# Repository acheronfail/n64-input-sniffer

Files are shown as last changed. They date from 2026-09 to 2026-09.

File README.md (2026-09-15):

# NintendoSpy N64 reader — ESP32

## How it works

The adapter reads input from up to four Nintendo 64 (N64) controllers and shows their buttons and stick positions in a browser.
It connects between the console and controllers without changing their signals.
The console must run and poll the controllers for input to appear.

## Setup

### Wiring

> [!WARNING]
> **Do not connect USB-C while the adapter is connected to the N64 console.**
> Fully disconnect the adapter from **all four console ports** before connecting USB-C to a computer or USB power source. Disconnect USB-C before reconnecting the adapter to the console.
>
> **Turning the console off is not enough.** USB power can backfeed the console’s 3.3V rail and potentially damage hardware. The 470 µF capacitor does not prevent backfeeding.

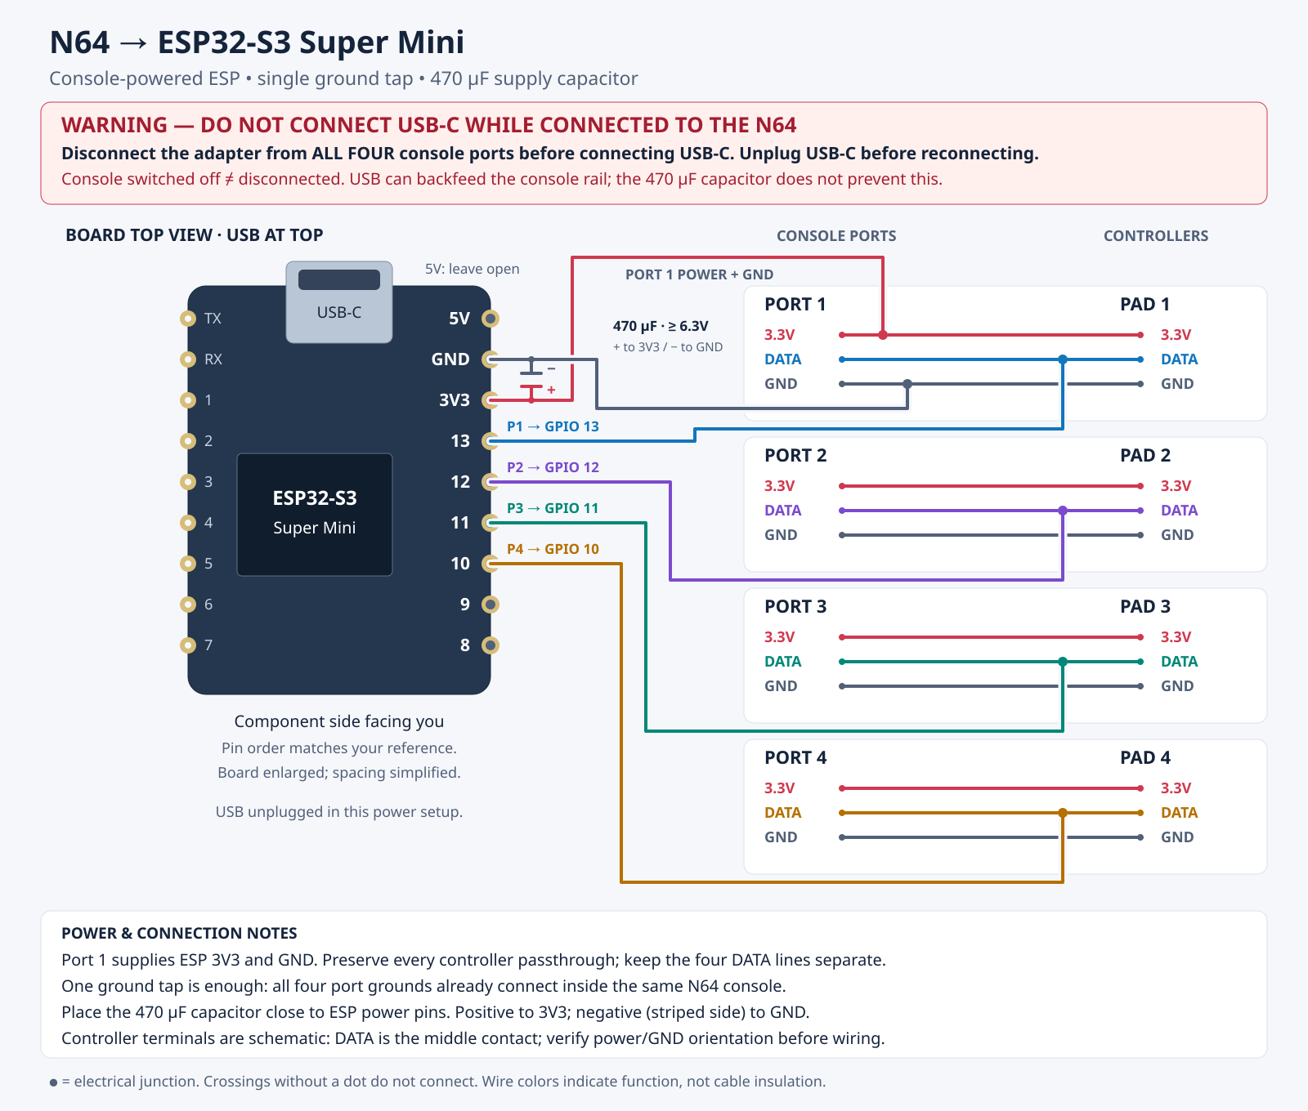
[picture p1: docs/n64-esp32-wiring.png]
Four-controller passthrough wiring


[Download the wiring diagram (SVG)](docs/n64-esp32-wiring.svg).
The diagram shows the component side of the Super Mini board, with USB at the top.

| Connection | ESP32 pin |
| --- | --- |
| Port 1 DATA (middle pin) | GPIO 13 |
| Port 2 DATA (middle pin) | GPIO 12 |
| Port 3 DATA (middle pin) | GPIO 11 |
| Port 4 DATA (middle pin) | GPIO 10 |
| 3.3V from one console port | 3V3 |
| GND from the same console port | GND |

1. Connect the DATA lines as shown in the diagram and table.
2. Connect one console port's 3.3V and GND to the ESP32.
   Keep each controller's power and ground passthrough connections.
3. Connect a **470 µF electrolytic capacitor**, rated at least **6.3V**, across ESP32 3V3 and GND.
   Place it close to the board with short leads.
   Connect **positive (+) to 3V3**. Connect **negative (striped side) to GND**.
4. Leave the ESP32 **5V pin unconnected**.

### Install the firmware

Install PlatformIO, Node.js 22.12 or later, and npm on your computer.

**Before connecting USB-C, disconnect the adapter from all four console ports—even if the console is off.**

1. Connect the ESP32 to your computer through USB-C.
2. From the project directory, build and upload the firmware:

   ```sh
   pio run -t upload
   ```

3. Disconnect USB-C.
4. Connect the adapter to the console and controllers.
5. Turn on the console.

### Connect to WiFi

1. On first boot, join the open **`N64Spy-Setup`** WiFi network from a phone or laptop.
   The setup page opens automatically.
2. Select your WiFi network on the setup page.
3. Enter the network password.
4. Save the credentials.
   The adapter saves them and reconnects automatically on later boots.
5. Open [n64spy.local](http://n64spy.local/) in a browser to view controller input.

To change networks, hold **BOOT** for about **3 seconds** at startup or during normal operation.
The adapter deletes the saved network and restarts WiFi setup.
You can also use the controller input code below.

## LED sequences

| State | LED sequence |
| ----- | --- |
| Normal power | Solid red, unless disabled with the input code below. |
| WiFi setup waits for credentials | Red, 500 ms on / 500 ms off, repeating. |
| WiFi connects or reconnects | Blue, 500 ms on / 500 ms off, repeating. |
| WiFi connected | Two green flashes, 250 ms on / 250 ms off, then the normal power setting. |
| WiFi connection failed or lost | Three red flashes, 125 ms on / 125 ms off, then the connection or setup sequence. |
| Command mode | Solid green for up to 5 seconds. |
| Command accepted | Four magenta flashes, 125 ms on / 125 ms off, then the command takes effect. |

WiFi and command feedback still show when the normal red power LED is disabled.
Command feedback takes priority over WiFi status.

## Controller input codes

Commands are available after the initial WiFi setup completes, while the console runs and polls the controller.
These button presses also reach the game.

1. Push **L + R + D-pad down** together on any controller.
   The LED turns **green** for up to **5 seconds**.
2. Within that time, push one command button on the **same controller**.
   You can release the entry combination first.

| Button | Action |
| --- | --- |
| **START** | Delete saved WiFi credentials and reboot into **N64Spy-Setup**. |
| **Z** | Switch the normal red power LED on or off. The setting stays saved after a reboot. |

An accepted command ends command mode and shows the magenta confirmation sequence before it takes effect.
If you already held the command button when command mode started, release it before you push it again.
Other buttons and simultaneous **START + Z** presses do not select a command.

If five seconds pass without a command, the LED returns to its normal setting.
To enter command mode again, release **L + R + D-pad down**, then push the combination again.

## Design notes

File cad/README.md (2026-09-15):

# CAD release

The v1.2 enclosure moves the ESP and its supports 2 mm toward the USB-C wall.
**Status: verified.** The owner printed v1.2 and marked it verified on 2026-09-15.
The v1.1 release stays available.

- [v1.2 FreeCAD model](Enclosure/Enclosure-v1.2.FCStd)
- [v1.2 print project](Enclosure/Enclosure-full-enclosure-v1.2-Orca-complete.3mf)

The tested **v1.1** enclosure leaves at least 2 mm between opposing keeper towers.
It moves the ESP window 4 mm toward the N64 edge and moves four closure bolts toward that edge.
The matching jig has an 18.1 mm connector gap.
**Status: verified.** The owner confirmed that both printed v1.1 parts work on 2026-09-15.
Physical verification applies to the retained v1.1 release files.
Generated reports describe digital checks only. Future geometry changes need new physical tests.

The physically tested [v1.0 enclosure](Enclosure/Enclosure-v1.0.FCStd) and [v1.0 print project](Enclosure/Enclosure-full-enclosure-v1.0-Orca-complete.3mf) remain unchanged.

- [Enclosure FreeCAD model](Enclosure/Enclosure-v1.1.FCStd)
- [Enclosure print-ready OrcaSlicer 3MF](Enclosure/Enclosure-full-enclosure-v1.1-Orca-complete.3mf)
- [Enclosure print and assembly instructions](Enclosure/README.md)
- [Soldering jig model, print project, and instructions](SolderingJig/README.md)
- Latest [female connector](n64-input-ControllerPortFemale.step) and [male connector](n64-input-ControllerPortMale.step) STEP models
- [Male housing-only reference](n64-input-ControllerPortMale-housing.step), the seating datum for the enclosure and jig

Both FreeCAD documents embed their shapes and references.
You need no external scans or build scripts to open them.
These documents contain saved solid models, not a history of constrained sketches.
Changes to the embedded parameter snapshot alone do not regenerate geometry.

The current Python build, geometry checks, and print export scripts remain beside each model.
See the [development instructions](DEVELOPMENT.md) to regenerate and revise the models.
Historical revisions and duplicate generated exports are omitted.

The enclosure contains reduced display meshes from [Wesk's N64 console scan](https://bitbuilt.net/forums/threads/n64-console-scan.5527/).
Their alignment is approximate.

See the [repository README](../README.md) for wiring and firmware.

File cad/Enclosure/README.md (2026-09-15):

# Enclosure v1.2

**Status: verified.** The owner printed v1.2 and marked it verified on 2026-09-15.
The owner tested the retained v1.1 print on 2026-09-15.

[FreeCAD model](Enclosure-v1.2.FCStd) · [Print-ready OrcaSlicer 3MF](Enclosure-full-enclosure-v1.2-Orca-complete.3mf)

v1.2 moves the ESP board, supports, and keeper 2 mm toward the USB-C wall.
The USB-C socket face moves from Y = 6.2 mm to Y = 8.2 mm.
The USB slot and lid window stay in place.
The existing board keeper fits the moved supports.

v1.1 gives wires at least 2 mm of space between the opposing keeper screw towers.
Connector tails are 18.094 mm apart at the center ports and 19.998 mm at the outer ports.
The matching soldering jig uses an 18.1 mm gap.
Female terminal passages remain 12.8 mm wide.

The ESP window, recess, and support ledge move 4 mm toward the N64-facing edge.
They stay centered from left to right.
v1.2 adds the board move described above.

Four of the six closure bolts now sit near the N64-facing edge: CAD (X, Y) = (±18, 3) and (±79.5, 2) mm.
The remaining pair stays near the female side at (±18, −48.2) mm.
This puts more fasteners along the edge that lifted.

Hardware quantities are unchanged.
The closure bosses stay inside the original 168 mm case outline.
Local reliefs let the two outer male keepers lift past the internal side bosses.

The original [v1.0 model](Enclosure-v1.0.FCStd) and [v1.0 print project](Enclosure-full-enclosure-v1.0-Orca-complete.3mf) remain unchanged.
Physical tests of v1.0 took place on 2026-09-13.

## Printing

The 3MF includes all 12 parts and sliced toolpaths across three plates.
It uses a Bambu Lab P1S 0.4 mm profile, Supertack bed, 0.16 mm layers, and a 0.20 mm first layer.

| Plate | Parts and material | Pauses |
| --- | --- | --- |
| 1 | Lower and upper shells, PLA | One pause to insert nuts |
| 2 | Four distinct male keepers, four identical female keepers, and one board keeper, PLA | None |
| 3 | One optional light window, PETG | None |

Parts have their print orientation in millimeters at 100% scale.
The four male keepers have one through four identification dimples and each fits a specific port.

1. Select the actual printer, bed, and filament before you print.
2. If you slice the project again, check the nut pause again.

## Hardware

- Six **M2 × 20 mm countersunk machine screws** and six M2 nuts for case closure.
- Sixteen **2 mm nominal × 8 mm countersunk screws suitable for plastic** for the eight port keepers, two each.
- Two normal M2 × 8 mm plastic screws for the board keeper.

Keeper clearance holes are 2.2 mm, with 90-degree countersinks sized to 4.2 mm heads.
Lower posts have 1.6 mm nominal printed pilot holes, 8 mm deep.
Select the screw/pilot combination for the actual printed material.
These holes are not modeled M2 metal threads.
Ordinary machine screws need suitably tapped posts or another threaded fastener arrangement.

The port-keeper screw heads must finish flush or below their keeper surfaces.
Nominal countersunk screw length is measured including the head.
An 8 mm keeper screw has approximately 6 mm of engagement below the 2 mm keeper bridge.
Tighten until the keeper seats on its posts.
Extra torque is not needed to squeeze the connector.

## Embedded closure nuts

Only the **six M2 closure nuts** remain embedded in the upper shell.
The supplied 3MF contains one native `M400 U1` pause on plate 1, before layer 88 at Z=14.12 mm.
Toolpath checks show that all six pocket caps start after the pause.
Plates 2 and 3 have no pauses.

Check the pause against the new slice before you print.
The nut-pocket cap must not start until the nuts are installed.

## Check the male connector

Check the real male mating portion against the extended CAD reference:

- 16 mm circular diameter, flattened to 12 mm high
- 12 mm projection from the housing
- Concentric with the housing
- Flat side down, opposite the housing's flat side (up)

The 0.35 mm mating-opening clearance is per axis.
The model does not include contacts.

## Install the connectors

1. With the lower shell open, seat one male connector, flat housing side up.
2. Fit its matching keeper and two keeper screws before the next port.
   Keepers 1–4 correspond to increasing CAD X: −64.04, −36.00, +36.00, +64.04 mm.
   The identification dimples sit on the rear screw bridge, toward the wiring cavity.
   From the controller/female side with the case upright, the order is left to right.
   From directly in front of the male tips, the order is reversed.
3. Repeat steps 1 and 2 for each remaining male port.
4. Seat each female connector in its existing groove.
5. Fit an identical female keeper and two screws to each female connector.
   No port must depend on the lid for retention.

## Install the board and check fit

1. Route wires through the spaces between the keeper posts.
2. Fit the board and its keeper, with USB toward the male connectors.
3. Keep wiring below the moving lid and clear of screw tips.
4. With the lid still off, gently check each port for lift and movement in both axial directions.
   Small clearance movement is expected. No housing must escape its keeper.
5. Make sure the console engagement is even and permits full insertion without force.

The retaining lip surrounds the mating portion near its root.
Thus, approximately 10 mm of the measured 12 mm projection remains beyond the local case face.
Check full insertion on the real console before final wiring and assembly.
The v1.1 geometry and toolpaths passed digital checks.
The owner confirmed that the printed v1.1 enclosure works on 2026-09-15.
The owner also printed v1.2 and marked it verified on 2026-09-15.

## Close the case

1. If desired, install the light window.
2. Lower the lid vertically.
3. Install the six closure screws.

To open the case again, remove only these closure screws.
Leave the port keepers attached.

## Existing electrical precaution

Fully disconnect the adapter from all four console ports before connecting USB-C. Disconnect USB-C before reconnecting to the console. Turning the console off alone does not disconnect its power rail; the enclosure is not an electrical interlock.

## Design changes

1. Edit `parameters.json` for exposed dimensions.
2. Edit `build.py` for geometry changes.
3. Run `build.FCMacro` in FreeCAD to produce `Enclosure-v1.2.FCStd` and print meshes.

See the [development instructions](../DEVELOPMENT.md) for checks, packaging, and slicing.
The saved model parameter snapshot does not recompute the design on its own.

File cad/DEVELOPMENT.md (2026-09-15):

# CAD development

The versioned FreeCAD models and print-ready 3MF files are the retained releases.
Enclosure builds write v1.2 models, working meshes, and reports. They preserve the v1.0 and v1.1 releases.
Soldering jig builds still write v1.1.
The enclosure's generated male connector STEP also stays in its own folder.
If the connector design changes, explicitly promote that STEP file to the parent reference.

## Runtime

The scripts need these tools:

- FreeCAD's Python runtime, with the `FreeCAD`, `Part`, and `Mesh` modules, for geometry scripts
- Python with NumPy for packaging and checks
- OrcaSlicer for slicing

The saved print projects use slices from OrcaSlicer 2.4.2.
The layout and pause checks assume the saved P1S 0.4 mm profile.
They also assume its 0.16 mm layers and 0.20 mm first layer.

In the commands below, `python` means the Python interpreter with FreeCAD support.
The name `orca-slicer` means the OrcaSlicer executable.
Run the commands from the repository root.
For example, use these paths for the macOS application bundles:

```sh
export PYTHONPATH="/Applications/FreeCAD.app/Contents/Resources/lib${PYTHONPATH:+:$PYTHONPATH}"
alias python='/Applications/FreeCAD.app/Contents/Resources/bin/python'
alias orca-slicer='/Applications/OrcaSlicer.app/Contents/MacOS/OrcaSlicer'
```

As an alternative, run the applicable `build.FCMacro` in FreeCAD.
The macro finds `build.py` relative to its own path.
You can run other geometry checks in FreeCAD's Python console:

1. Set `__file__` to the script's absolute path.
2. Run the script with `exec(compile(...))`.

## Enclosure

1. Edit [Enclosure/parameters.json](Enclosure/parameters.json) for dimensions, or [Enclosure/build.py](Enclosure/build.py) for construction changes.
2. If the design changes, adjust any applicable fixed construction dimensions and fit checks in the source.

Each build reads the parameters again.
Some construction dimensions and fit checks remain fixed in the source.

Run the build, checks, and packaging scripts in this order:

```sh
python cad/Enclosure/build.py
python cad/Enclosure/check_fit.py
python cad/Enclosure/check_nut_seats.py
python cad/Enclosure/check_retention.py
python cad/Enclosure/check_mesh.py
python cad/Enclosure/package_print.py
python cad/Enclosure/create_3mf.py
```

The build checks that each part is a valid single solid and checks interference in the assembly.
Other checks cover these features:

- Terminal passages and male projection orientation
- Keeper installation and retention
- Lid removal and USB access
- Nut walls and insertion
- Mesh closure

The checks use the current geometry without loading discarded revisions.
Each generated revision needs its own physical fit tests.

`package_print.py` produces STL files in their print orientation, a manifest, and an assembly README in `Enclosure/print/full-enclosure-v1.2/`.
It also produces a ZIP.
`create_3mf.py` reads profiles from the retained v1.0 3MF and builds a new unsliced project from the new meshes.
It does not reuse old toolpaths.

Run the slicer and slice checks:

```sh
mkdir -p cad/Enclosure/slice/v1.2
orca-slicer --slice 0 --outputdir cad/Enclosure/slice/v1.2 --export-3mf Enclosure-full-enclosure-v1.2-Orca-complete.3mf cad/Enclosure/Enclosure-v1.2-Orca-input.3mf
python cad/Enclosure/check_nut_pause.py
python cad/Enclosure/verify_print.py
```

The two slice checks default to `Enclosure/slice/v1.2/`.
To check another Orca command-line output directory, pass `--slice-dir PATH`.
That directory must contain the exported 3MF and plate G-code files, plus `result.json` when Orca writes it.
The checks support Orca 2.4.0 through embedded slice metadata.
If Orca asks to open the 2.4.2 project, use `--allow-newer-file`.

The slice checks compare geometry with the generated STL files.
They also check plate placement, new slice warnings, and the exact order of the nut pause and cap extrusion.
They report existing profile warnings separately.
The retained enclosure project already contains `bed_temperature_too_high_than_filament`.

Check the bed/filament temperatures before printing; restoring the pipeline does not alter the tested project settings.

The checks fail if changed dimensions or settings invalidate the fixed layout, 14.12 mm pause height, or layer 88.
If this occurs, update the layout and pause checks together.
Then inspect the new slice.

## Soldering jig

The jig's dimensions are in [SolderingJig/build.py](SolderingJig/build.py).
The build uses the female and housing-only male STEP references directly.
It builds its own mating projection.

Run the build, checks, and slicer in this order:

```sh
python cad/SolderingJig/build.py
python cad/SolderingJig/check_fit.py
python cad/SolderingJig/create_3mf.py
mkdir -p cad/SolderingJig/slice/v1.1
orca-slicer --slice 0 --outputdir cad/SolderingJig/slice/v1.1 --export-3mf N64-Soldering-Jig-v1.1.3mf cad/SolderingJig/N64-Soldering-Jig-v1.1-input.3mf
python cad/SolderingJig/verify_print.py
```

The build and fit check cover solid validity, assembly interference, connector retention and rotation, clamp insertion, and terminal access.
The print check covers mesh geometry, layout, watertightness, and the absence of supports or pauses.
It accepts `--slice-dir PATH`, as the enclosure print check does.

## References and releases

The parent connector STEP files are the only external construction geometry.
The enclosure build copies the optional embedded console display meshes from the retained release, including their original placements.
It needs no historical scans, measurement reports, or revision folders.
This overlay is approximate.
It does not give a new console-clearance check after design changes.

Git ignores working STL/STEP exports, ZIPs, input 3MFs, reports, and slice directories.
The project retains named FreeCAD release models and sliced 3MFs.

To make a release:

1. Review the geometry and sliced project.
2. Test the physical changes.
3. Explicitly save a new named FreeCAD release.
4. Promote its checked sliced 3MF.
5. Update versioned filenames in the scripts and documentation.

New parameters saved in a FreeCAD document alone do not regenerate the solids.

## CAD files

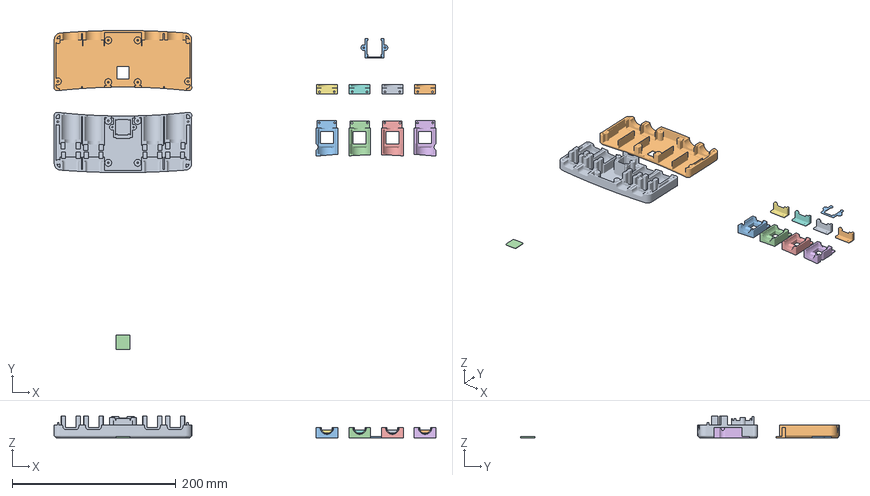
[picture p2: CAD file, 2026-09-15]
cad/Enclosure/Enclosure-full-enclosure-v1.2-Orca-complete.3mf
466.8 x 389.8 x 26.8 mm
LowerShell.stl
UpperShell.stl
MalePortKeeper1.stl
MalePortKeeper2.stl
MalePortKeeper3.stl
MalePortKeeper4.stl
FemalePortKeeper.stl x 4
BoardKeeper.stl
LightWindow.stl

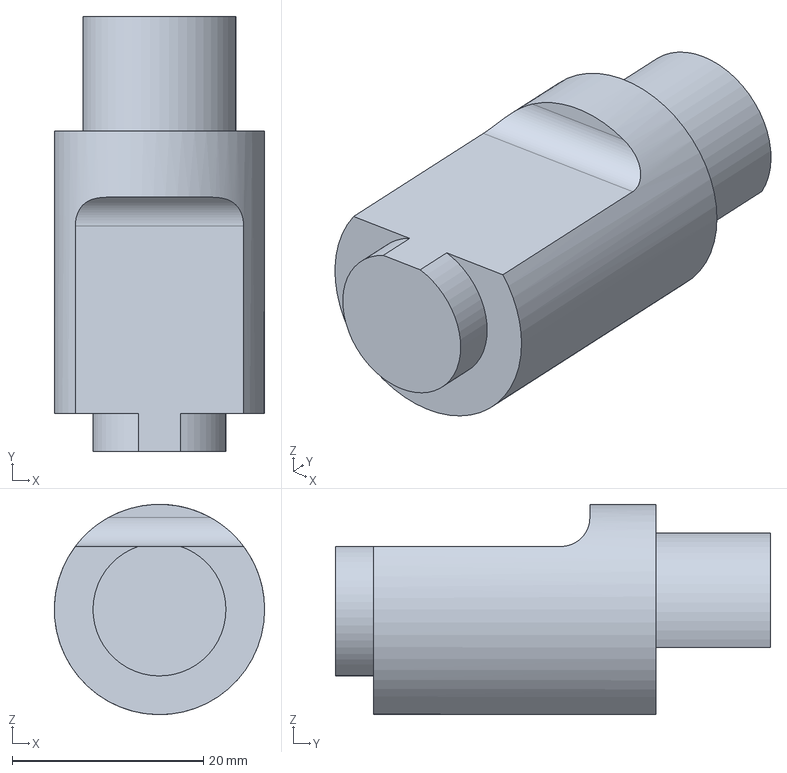
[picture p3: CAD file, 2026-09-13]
cad/n64-input-ControllerPortMale.step
22.0 x 45.5 x 22.0 mm

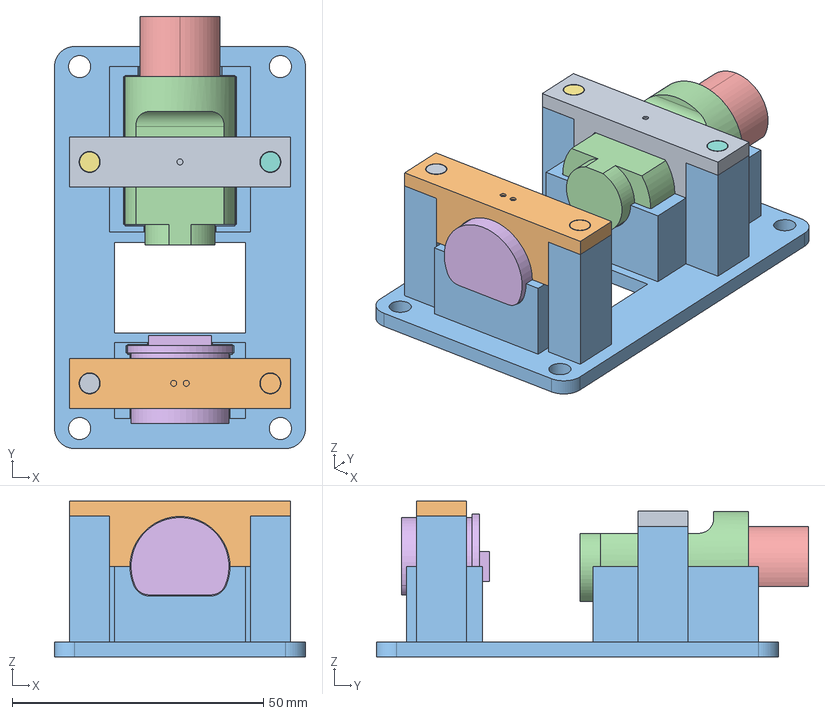
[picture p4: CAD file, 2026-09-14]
cad/SolderingJig/N64-Soldering-Jig-v1.1.FCStd
50.0 x 86.1 x 31.0 mm
MaleClamp
FemaleClamp
JigBase
MaleHousing
MaleMatingPortion
FemaleHousing
MaleClampLeftScrew
MaleClampRightScrew
FemaleClampLeftScrew
FemaleClampRightScrew

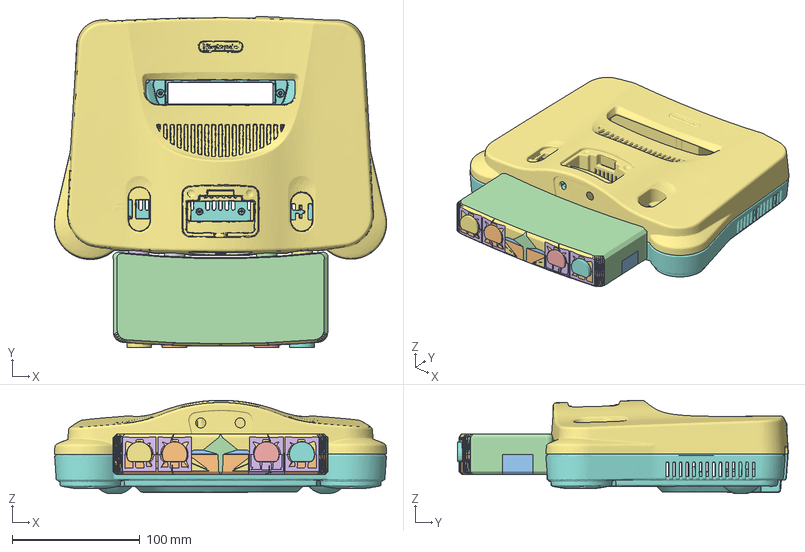
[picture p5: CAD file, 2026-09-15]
cad/Enclosure/Enclosure-v1.2.FCStd
260.2 x 259.2 x 73.2 mm
MalePortKeeper1
MalePortKeeper2
MalePortKeeper3
MalePortKeeper4
FemalePortKeeper1
FemalePortKeeper2
FemalePortKeeper3
FemalePortKeeper4
PCB keeper · two normal M2 x 8 screws · print flat
Lower shell · extended housing seats · independent keeper posts
Upper shell · independent connector retention · no clamp hardware
Optional translucent LED window
MalePort1
MaleMatingProjection1
FemalePort1
MalePort2
MaleMatingProjection2
FemalePort2
MalePort3
MaleMatingProjection3
FemalePort3
MalePort4
MaleMatingProjection4
FemalePort4
MaleKeeperScrew1L
MaleKeeperScrew1R
MaleKeeperScrew2L
MaleKeeperScrew2R
MaleKeeperScrew3L
MaleKeeperScrew3R
MaleKeeperScrew4L
MaleKeeperScrew4R
FemaleKeeperScrew1L
FemaleKeeperScrew1R
FemaleKeeperScrew2L
FemaleKeeperScrew2R
FemaleKeeperScrew3L
FemaleKeeperScrew3R
FemaleKeeperScrew4L
FemaleKeeperScrew4R
ESP32BoardEnvelope
ESP32ComponentKeepout
USBCEnvelope
OuterContourLoft
InteriorLoft
ConnectorCollars
CapturedConnectorSeats
LEDWindowSupportTaper
USBSeamTongue
MaleKeeperPosts1
MaleKeeperPosts2
MaleKeeperPosts3
MaleKeeperPosts4
FemaleKeeperPosts1
FemaleKeeperPosts2
FemaleKeeperPosts3
FemaleKeeperPosts4
BoardCradle
PRINT FIRST · Four-plug lower alignment gauge
RearAlignmentGaugeUpper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

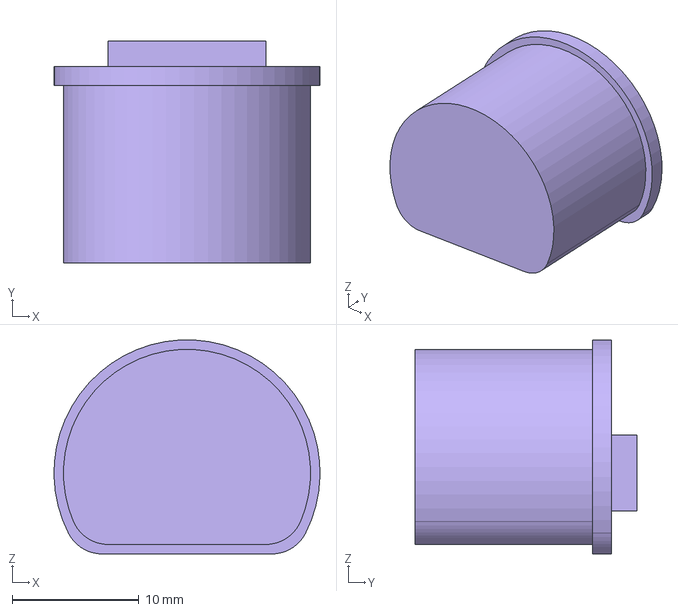
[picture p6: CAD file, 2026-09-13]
cad/n64-input-ControllerPortFemale.step
21.0 x 17.5 x 16.9 mm

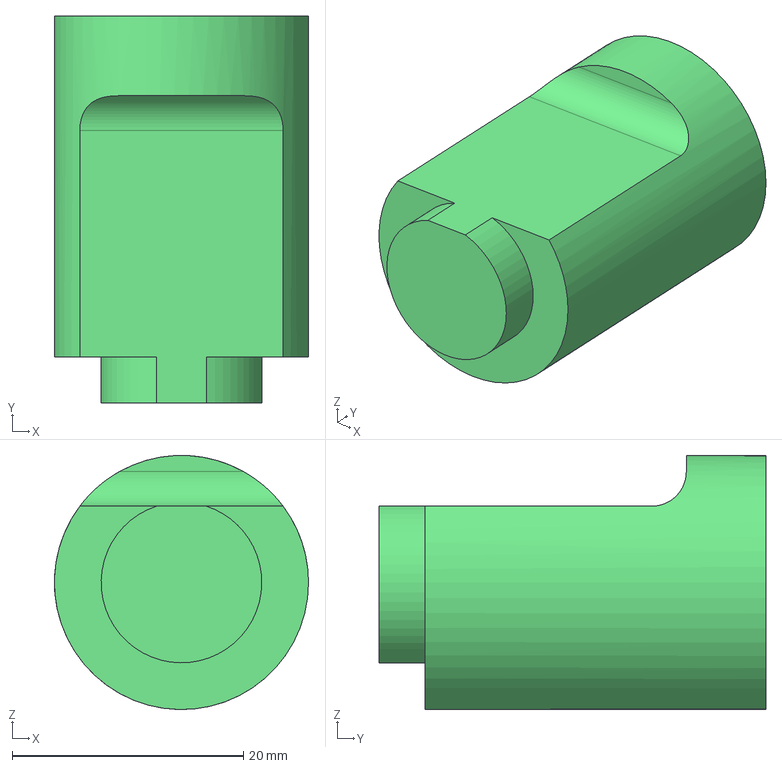
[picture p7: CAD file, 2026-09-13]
cad/n64-input-ControllerPortMale-housing.step
22.0 x 33.5 x 22.0 mm

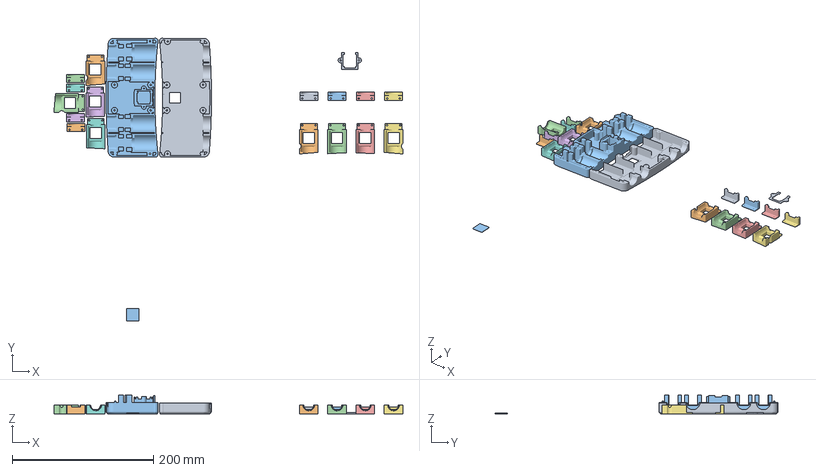
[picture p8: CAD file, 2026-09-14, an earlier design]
cad/Enclosure/Enclosure-full-enclosure-v1.1-Orca-complete.3mf
494.0 x 400.3 x 26.8 mm
UpperShell.stl
MalePortKeeper1.stl x 2
LowerShell.stl
MalePortKeeper2.stl x 2
MalePortKeeper3.stl x 2
MalePortKeeper4.stl x 2
FemalePortKeeper.stl x 8
BoardKeeper.stl
LightWindow.stl

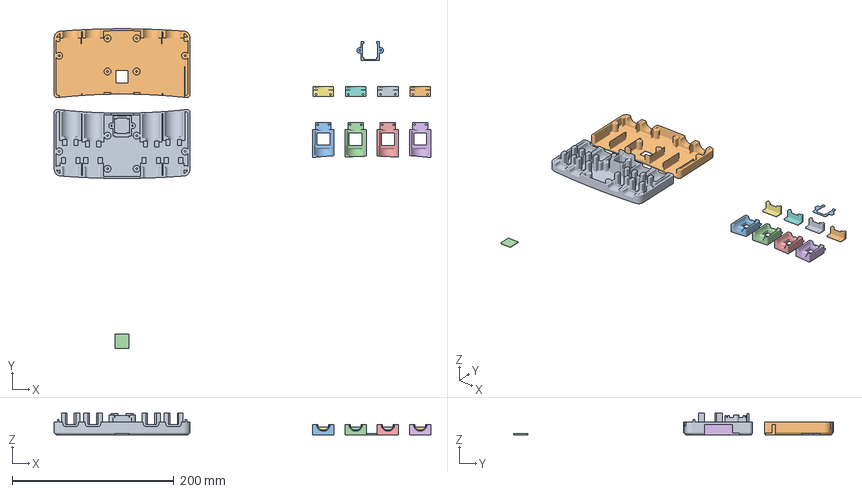
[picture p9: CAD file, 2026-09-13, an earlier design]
cad/Enclosure/Enclosure-full-enclosure-v1.0-Orca-complete.3mf
466.8 x 395.7 x 26.8 mm
LowerShell.stl
UpperShell.stl
MalePortKeeper1.stl
MalePortKeeper2.stl
MalePortKeeper3.stl
MalePortKeeper4.stl
FemalePortKeeper.stl x 4
BoardKeeper.stl
LightWindow.stl

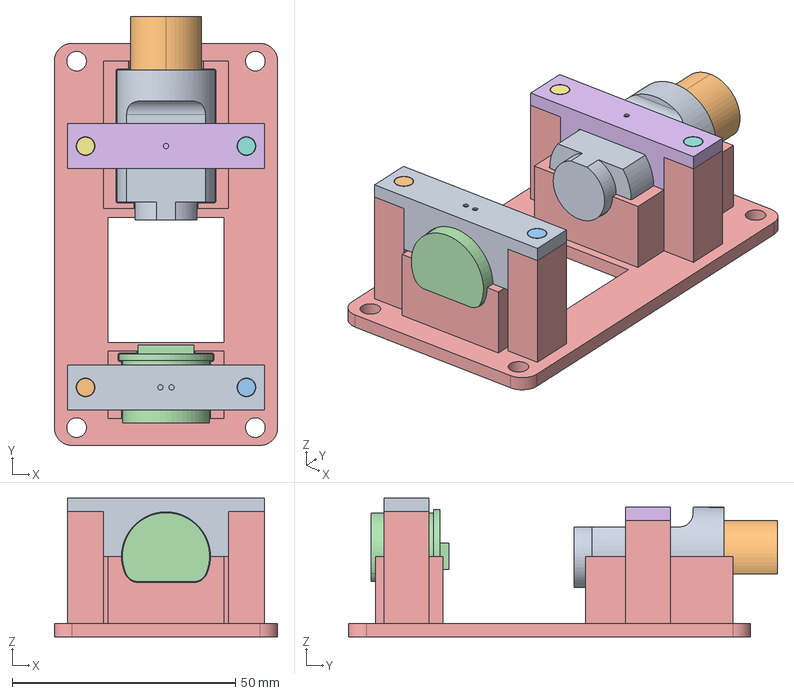
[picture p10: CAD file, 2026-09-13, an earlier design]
cad/SolderingJig/N64-Soldering-Jig-v1.FCStd
50.0 x 96.0 x 31.0 mm
FemaleClamp
FemaleClampLeftScrew
FemaleClampRightScrew
FemaleHousing
JigBase
MaleClamp
MaleClampLeftScrew
MaleClampRightScrew
MaleHousing
MaleMatingPortion

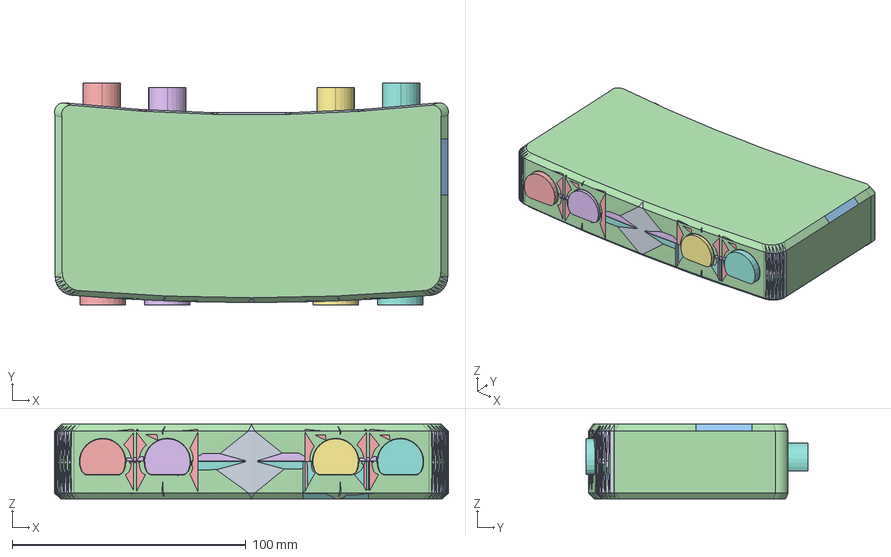
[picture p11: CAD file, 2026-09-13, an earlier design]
cad/Enclosure/Enclosure-v1.0.FCStd
168.6 x 94.8 x 32.0 mm
BoardCradle
BoardFitCoupon
PCB keeper · two normal M2 x 8 screws · print flat
CapturedConnectorSeats
ConnectorCollars
ESP32BoardEnvelope
ESP32ComponentKeepout
FemaleFitCoupon
FemaleKeeperPosts1
FemaleKeeperPosts2
FemaleKeeperPosts3
FemaleKeeperPosts4
FemaleKeeperScrew1L
FemaleKeeperScrew1R
FemaleKeeperScrew2L
FemaleKeeperScrew2R
FemaleKeeperScrew3L
FemaleKeeperScrew3R
FemaleKeeperScrew4L
FemaleKeeperScrew4R
FemalePort1
FemalePort2
FemalePort3
FemalePort4
FemalePortKeeper1
FemalePortKeeper2
FemalePortKeeper3
FemalePortKeeper4
InteriorLoft
LEDWindowSupportTaper
Optional translucent LED window
Lower shell · extended housing seats · independent keeper posts
MaleKeeperPosts1
MaleKeeperPosts2
MaleKeeperPosts3
MaleKeeperPosts4
MaleKeeperScrew1L
MaleKeeperScrew1R
MaleKeeperScrew2L
MaleKeeperScrew2R
MaleKeeperScrew3L
MaleKeeperScrew3R
MaleKeeperScrew4L
MaleKeeperScrew4R
MaleMatingProjection1
MaleMatingProjection2
MaleMatingProjection3
MaleMatingProjection4
MalePort1
MalePort2
MalePort3
MalePort4
MalePortKeeper1
MalePortKeeper2
MalePortKeeper3
MalePortKeeper4
OuterContourLoft
PRINT FIRST · Four-plug lower alignment gauge
RearAlignmentGaugeUpper
USBCEnvelope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

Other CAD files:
cad/Enclosure/Enclosure-v1.1.FCStd
cad/SolderingJig/N64-Soldering-Jig-v1.1.3mf
cad/SolderingJig/N64-Soldering-Jig-v1.3mf

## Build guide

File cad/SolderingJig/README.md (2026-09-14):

# N64 soldering jig v1.1

This compact fixture holds one male/female pair with their wiring ends toward a central work area.
The 50 × 80.1 mm base supports both housings on keyed seats.
Two removable contour clamps prevent lift and rotation.
The male clamp grips the middle flat portion, away from the curved front lip.
Lower shoulders and flange grooves resist axial movement.

Connector axes are 18 mm above the bench.
A 26 × 18.1 mm opening sits under the wiring area.
The female rear passage is 12.8 mm wide.

[Print-ready 3MF](N64-Soldering-Jig-v1.1.3mf) · [FreeCAD model](N64-Soldering-Jig-v1.1.FCStd)

## Printing

The 3MF contains one each of `JigBase`, `MaleClamp`, and `FemaleClamp`.
The parts already have their print orientation: base upright and clamps upside down, with their flat top faces on the bed.
Print at 100% scale.
The parts need no supports, embedded nuts, or pauses.

The 3MF uses the current enclosure's Bambu Lab P1S 0.4 mm printer and Supertack bed profile.
It uses PLA slot 5, 0.16 mm layers, a 0.20 mm first layer, three walls, and 15% infill.
Make sure the selected filament matches the loaded filament.
Keep the soldering iron away from the plastic fixture.

## Hardware

Use **four 2 mm nominal × 8 mm countersunk screws suitable for plastic**, two per clamp.
The enclosure's port keepers use the same screws.
Holes are 1.6 mm pilots, with 2.2 mm clamp clearances and 4.2 mm 90-degree head seats.
The 3 mm clamp tabs leave about 5 mm of screw engagement.
The clamps need no nuts.

## Load the connectors

1. Place the jig on the bench.
   The four 4.4 mm corner holes are optional bench mounts.
   A small bench clamp can also hold the side rails.
2. Seat the male housing flat side up in the longer saddle.
   Its black mating portion points outward, with its flat side down.
   The wiring end points into the central opening.
3. Seat the female port in the short saddle to match the keyed lower contour and flange groove.
   Its mating opening faces outward. Its terminals point toward the male wiring end.
4. Install the blue male clamp (one identification dimple) and the female clamp (two dimples).
5. Tighten their screws gently until the tabs seat on the posts.
   Do not use the screws to force an incorrectly oriented connector into place.

## Solder and remove the pair

1. Solder the pair through the central work area.
2. Let the joints cool.
3. Remove the four screws.
4. Lift both clamps and the connected pair out of the jig.

## Fit and model details

The fixture uses the supplied connector housing shapes with 0.22 mm clearance.
CAD checks cover retention in all six translation directions, resistance to rolling, clamp installation clearance, and clear paths to the terminals.
The model does not include individual metal terminals or wires.
**Status: verified.** The owner printed v1.1 and confirmed that it works on 2026-09-15.

The FreeCAD document embeds the connector references and all three print solids.
It opens without external models or scripts.

The 18.1 mm connector gap matches enclosure v1.1, which leaves at least 2 mm between its opposing keeper towers.
The original [v1 model](N64-Soldering-Jig-v1.FCStd) and [v1 print project](N64-Soldering-Jig-v1.3mf) remain unchanged.

## Design changes

1. Edit `build.py`.
2. Run `build.FCMacro` in FreeCAD to produce `N64-Soldering-Jig-v1.1.FCStd` and print meshes.

See the [development instructions](../DEVELOPMENT.md) for checks and 3MF generation.
The versioned release files remain unchanged until an explicit replacement.

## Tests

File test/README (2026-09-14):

# Tests

Run all firmware host tests from the repository root:

    sh scripts/test_host.sh

The tests need a C++11 compiler (`c++`, or set CXX).
The script builds binaries in a temporary folder and removes them on exit.
These tests use the same headers as the firmware.
They need no board, Arduino software development kit (SDK), or network.

## Test coverage

- `n64_decoder_test.cpp`: Literal poll/response fixtures converted to remote control peripheral (RMT) pulse items.
  Tests cover both level orders, timing limits, each button and axis bit, invalid commands and stop bits, and reserved bits.
  They also cover short and long captures, and noise.
  The fixtures are synthetic. They are not recordings from a physical controller.
  The decoder skips malformed cells, as before.
  The firmware checks reserved bits separately before it handles commands or publishes state.
- `ws_delivery_test.cpp`: Independent retries for fast and slow clients, and recovery of the final state without new input.
  Tests also cover failed sends, combined updates that keep the latest state, initial snapshots, fairness, and rate limits.
  Further tests cover removal and recovery of slow clients, reconnects, capacity, and rollover of the microsecond clock.
- `controller_commands_test.cpp`: Command ownership, button edges, deadlines, confirmation flashes, actions that occur once, and timer rollover.
- `wifi_status_led_test.cpp`: WiFi status patterns and priority between commands, WiFi status, and the power LED.

## Other checks

Run web unit tests with `cd web && npm test`.
Build the firmware for integration checks with `pio run -e esp32-s3-devkitc-1`.
Hardware capture timing and actual network/AsyncTCP behavior still need a board test.
The host delivery tests check the scheduling policy. They do not test sockets.

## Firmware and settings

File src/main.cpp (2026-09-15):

/**
 * Ported to ESP32 from NintendoSpy N64.
 *
 * This passive bus sniffer reads the single data wire between an N64 console
 * and a controller. It decodes the controller's response to the console's poll
 * command (0x01). The ESP32 only reads the line. It never drives the line.
 *
 * Each N64 bit is a ~4us pulse on an open-collector line that stays high when idle.
 * A '0' is low for ~3us and high for ~1us.
 * A '1' is low for ~1us and high for ~3us.
 * The ESP32's remote control peripheral (RMT) timestamps received pulse widths
 * in hardware. The firmware decodes each bit from the low pulse duration.
 *
 * Each polled frame starts with the console's 9-bit prefix: the 0x01 command
 * byte 0000_0001 and a stop bit, giving 0000_0001 1.
 * The controller's 32-bit response comes immediately after the prefix.
 */

#include <Arduino.h>
#include <atomic>
#include <ArduinoOTA.h>
#include <ESPAsyncWebServer.h>
#include <ESPmDNS.h>
#include <Preferences.h>
#include <WiFi.h>
#include <WiFiManager.h>
#include <driver/rmt.h>
#include <esp_timer.h>
#include <freertos/ringbuf.h>

#include "web_ui.h"
#include "controller_commands.h"
#include "wifi_status_led.h"
#include "n64_decoder.h"
#include "ws_delivery.h"

static ControllerCommands controllerCommands;
static std::atomic<bool> powerLedEnabled{true};
static std::atomic<bool> wifiLedConnected{false};
static std::atomic<bool> wifiLedPortal{false};
static std::atomic<uint32_t> wifiLedFailures{0};
static std::atomic<ControllerCommands::Led> commandLed{ControllerCommands::Led::Normal};
static void processCommandFrame(size_t controller, const uint8_t *frame);

// ---------- WiFi / setup portal ---------------------------------------------
// The firmware contains no fixed credentials. On first boot or after a failed
// reconnect, the ESP32 starts an open access point (AP) named AP_NAME.
// Join it from a phone or laptop. Select your network in the captive portal.
// Enter the password. WiFiManager saves it in flash.
// The ESP32 reconnects automatically on later boots.
//
// Hold BOOT (WIFI_RESET_PIN) for WIFI_RESET_HOLD_MS to delete the saved network
// and reboot into the setup portal. This applies at startup or during normal operation.
#define AP_NAME "N64Spy-Setup"
#define MDNS_HOST "n64spy"
#define WIFI_RESET_PIN 0       // BOOT button on most ESP32 dev boards
#define WIFI_RESET_HOLD_MS 3000 // hold duration to delete WiFi credentials and restart

// ---------- Over-the-air updates --------------------------------------------
// After connection, the ESP32 accepts firmware uploads over WiFi without USB.
// PlatformIO command: `pio run -e esp32dev_ota -t upload`.
// The device advertises OTA_HOSTNAME.local through multicast DNS (mDNS).
// Set upload_port to that name or its IP address in platformio.ini.
//
// OTA_PASSWORD controls authentication for over-the-air (OTA) updates.
// Leave it empty to disable authentication.
// For a password, set OTA_PASSWORD. Pass --auth=<password> through upload_flags in platformio.ini.
#define OTA_HOSTNAME MDNS_HOST
#define OTA_PASSWORD ""

// ---------- Wiring -----------------------------------------------------------
// Connect this GPIO to the N64 controller DATA line, the middle pin of the 3-pin N64 connector.
// The N64 data line uses 3.3V logic with a pull-up on the console side.
// It connects directly to an ESP32 input pin without level shifting.
// Share a common ground with the console/controller.
//
// Up to 4 controller data lines, one per RMT RX channel.
#define N64_CONTROLLER_COUNT 4
#define N64_PIN_1 13
#define N64_PIN_2 12
#define N64_PIN_3 11
#define N64_PIN_4 10

#define SERIAL_BAUD 115200

// Maximum time loop() waits for a frame with interrupts enabled before it returns.
// This limit lets the interrupt watchdog and real-time operating system (RTOS)
// run when the line is idle or no console is attached.
#define FRAME_WAIT_US 5000

// End RMT reception after the bus stays at one level for this duration.
#define RMT_IDLE_THRESHOLD_US 12
static constexpr uint32_t kN64RmtTicksPerUs = 8;

// On ESP32-S3 with the legacy RMT API, channels 4-7 are RX-capable.
static constexpr int kN64Pins[N64_CONTROLLER_COUNT] = {
  N64_PIN_1, N64_PIN_2, N64_PIN_3, N64_PIN_4};
static constexpr rmt_channel_t kN64Channels[N64_CONTROLLER_COUNT] = {
  RMT_CHANNEL_4, RMT_CHANNEL_5, RMT_CHANNEL_6, RMT_CHANNEL_7};
static RingbufHandle_t n64RmtRingbufs[N64_CONTROLLER_COUNT] = {nullptr, nullptr,
                                 nullptr, nullptr};

// The HTTP server serves the user interface (UI), which listens to the WebSocket.
// Both run in the AsyncTCP task on the other core and do not block pulse capture.
static AsyncWebServer server(80);
static AsyncWebSocket ws("/ws");

// Last captured state per controller, for change detection and serial logging.
// WsDelivery owns a separate snapshot for browser delivery.
static uint8_t lastPayload[N64_CONTROLLER_COUNT][4] = {
  {0, 0, 0, 0}, {0, 0, 0, 0}, {0, 0, 0, 0}, {0, 0, 0, 0}};
static WsDelivery wsDelivery;
static portMUX_TYPE wsDeliveryMux = portMUX_INITIALIZER_UNLOCKED;
static uint32_t wsDiscardCount = 0;
static uint32_t wsDisconnectCount = 0;
static uint32_t wsSlowCloseCount = 0;
static uint32_t wifiDisconnectCount = 0;
static uint32_t lastWsDiagAtMs = 0;

// A port is "connected" if it recently received valid poll-response frames.
// This detects activity, not the cable connection itself.
#define PORT_ACTIVITY_TIMEOUT_MS 1500
#define PORT_PROBE_INTERVAL_MS 100
#define PORT_PROBE_WINDOW_MS 30
static bool controllerConnected[N64_CONTROLLER_COUNT] = {false, false, false,
                                                         false};
static uint32_t controllerLastSeenMs[N64_CONTROLLER_COUNT] = {0, 0, 0, 0};
static bool controllerRxRunning[N64_CONTROLLER_COUNT] = {false, false, false,
                                                         false};
static bool controllerProbing[N64_CONTROLLER_COUNT] = {false, false, false,
                                                       false};
static uint32_t controllerProbeStartedMs[N64_CONTROLLER_COUNT] = {0, 0, 0, 0};
static uint32_t controllerLastProbeAtMs[N64_CONTROLLER_COUNT] = {0, 0, 0, 0};

/** Configure one controller's RMT RX channel for 0.125us pulse capture. */
static bool startRmtCapture(size_t controller) {
  if (controller >= N64_CONTROLLER_COUNT) {
    return false;
  }

  rmt_config_t cfg = {};
  cfg.rmt_mode = RMT_MODE_RX;
  cfg.channel = kN64Channels[controller];
  cfg.gpio_num = (gpio_num_t)kN64Pins[controller];
  cfg.clk_div = 80 / kN64RmtTicksPerUs;
  // ESP32-S3 legacy RMT limits memory per group.
  // With 4 receive (RX) channels active, use one block per channel to configure all channels.
  cfg.mem_block_num = 1;
  cfg.flags = 0;
  cfg.rx_config.idle_threshold = RMT_IDLE_THRESHOLD_US * kN64RmtTicksPerUs;
  // The filter uses APB clock periods, separate from the capture tick duration.
  cfg.rx_config.filter_en = true;
  cfg.rx_config.filter_ticks_thresh = 1;

  esp_err_t err = rmt_config(&cfg);
  if (err != ESP_OK) {
    Serial.printf("RMT config failed (pad %u): %d\n", (unsigned)(controller + 1),
                  (int)err);
    return false;
  }

  err = rmt_driver_install(kN64Channels[controller], 4096, 0);
  if (err != ESP_OK) {
    Serial.printf("RMT driver install failed (pad %u): %d\n",
                  (unsigned)(controller + 1), (int)err);
    return false;
  }

  err = rmt_get_ringbuf_handle(kN64Channels[controller],
                               &n64RmtRingbufs[controller]);
  if (err != ESP_OK || n64RmtRingbufs[controller] == nullptr) {
    Serial.printf("RMT ringbuf setup failed (pad %u): %d\n",
                  (unsigned)(controller + 1), (int)err);
    return false;
  }

  controllerRxRunning[controller] = false;
  controllerProbing[controller] = false;
  return true;
}

static bool startControllerRx(size_t controller) {
  if (controller >= N64_CONTROLLER_COUNT) {
    return false;
  }
  if (controllerRxRunning[controller]) {
    return true;
  }

  esp_err_t err = rmt_rx_start(kN64Channels[controller], true);
  if (err != ESP_OK) {
    Serial.printf("RMT RX start failed (pad %u): %d\n",
                  (unsigned)(controller + 1),
                  (int)err);
    return false;
  }

  controllerRxRunning[controller] = true;
  return true;
}

static void stopControllerRx(size_t controller) {
  if (controller >= N64_CONTROLLER_COUNT || !controllerRxRunning[controller]) {
    return;
  }

  esp_err_t err = rmt_rx_stop(kN64Channels[controller]);
  if (err != ESP_OK) {
    Serial.printf("RMT RX stop failed (pad %u): %d\n", (unsigned)(controller + 1),
                  (int)err);
  }
  controllerRxRunning[controller] = false;
}

/** Poll one controller's RMT ring buffer and decode one N64 frame if present. */
static bool readFrameFromRmt(size_t controller, uint8_t frame[N64_FRAMEBITS]) {
  if (controller >= N64_CONTROLLER_COUNT || n64RmtRingbufs[controller] == nullptr) {
    return false;
  }

  bool foundFrame = false;

  for (;;) {
    size_t rxSize = 0;
    rmt_item32_t *items = (rmt_item32_t *)xRingbufferReceive(
        n64RmtRingbufs[controller], &rxSize, 0);
    if (items == nullptr) {
      break;
    }

    if (rxSize >= sizeof(rmt_item32_t)) {
      uint8_t latestFrame[N64_FRAMEBITS];
      if (decodeFrameFromRmtItems(items, rxSize / sizeof(rmt_item32_t),
                                  latestFrame, kN64RmtTicksPerUs)) {
        // Process every queued frame so emptying the queue does not hide button edges.
        processCommandFrame(controller, latestFrame);
        memcpy(frame, latestFrame, N64_FRAMEBITS);
        foundFrame = true;
      }
    }

    vRingbufferReturnItem(n64RmtRingbufs[controller], (void *)items);
  }

  return foundFrame;
}

/** Decoded N64 controller state. */
struct N64State {
  bool a, b, z, start;
  bool up, down, left, right;
  bool l, r;
  bool cUp, cDown, cLeft, cRight;
  int8_t stickX;
  int8_t stickY;
};

/**
 * Bit positions in the 32-bit controller response match NintendoSpy's
 * Readers/Nintendo64.cs. The controller does not use indices 8 and 9.
 */
enum N64ResponseBit {
  RESP_A = 0,
  RESP_B,
  RESP_Z,
  RESP_START,
  RESP_UP,
  RESP_DOWN,
  RESP_LEFT,
  RESP_RIGHT,
  RESP_L = 10,
  RESP_R,
  RESP_C_UP,
  RESP_C_DOWN,
  RESP_C_LEFT,
  RESP_C_RIGHT,
  RESP_STICK_X = 16, // 8-bit signed, MSB-first
  RESP_STICK_Y = 24, // 8-bit signed, MSB-first
};

/** Decode the controller response that follows the prefix in `frame`. */
static N64State decodeState(const uint8_t *frame) {
  const uint8_t *r = frame + N64_PREFIX; // start of the 32-bit response
  N64State s;
  s.a = r[RESP_A];
  s.b = r[RESP_B];
  s.z = r[RESP_Z];
  s.start = r[RESP_START];
  s.up = r[RESP_UP];
  s.down = r[RESP_DOWN];
  s.left = r[RESP_LEFT];
  s.right = r[RESP_RIGHT];
  s.l = r[RESP_L];
  s.r = r[RESP_R];
  s.cUp = r[RESP_C_UP];
  s.cDown = r[RESP_C_DOWN];
  s.cLeft = r[RESP_C_LEFT];
  s.cRight = r[RESP_C_RIGHT];
  s.stickX = (int8_t)readByte(r, RESP_STICK_X);
  s.stickY = (int8_t)readByte(r, RESP_STICK_Y);
  return s;
}

/** Print one controller's state over serial in a readable format. */
static void printState(size_t controller, const N64State &s) {
  char buf[160];
  int n = 0;
  n += snprintf(buf + n, sizeof(buf) - n, "[N64 %u]",
                (unsigned)(controller + 1));

#define BTN(label, field)                                                      \
  do {                                                                         \
    if (s.field)                                                               \
      n += snprintf(buf + n, sizeof(buf) - n, " " label);                      \
  } while (0)
  BTN("A", a);
  BTN("B", b);
  BTN("Z", z);
  BTN("START", start);
  BTN("UP", up);
  BTN("DOWN", down);
  BTN("LEFT", left);
  BTN("RIGHT", right);
  BTN("L", l);
  BTN("R", r);
  BTN("C-UP", cUp);
  BTN("C-DOWN", cDown);
  BTN("C-LEFT", cLeft);
  BTN("C-RIGHT", cRight);
#undef BTN

  n += snprintf(buf + n, sizeof(buf) - n, "  stick=(%d, %d)", s.stickX,
                s.stickY);
  Serial.println(buf);
}

static bool anyPendingPackets() {
  portENTER_CRITICAL(&wsDeliveryMux);
  const bool pending = wsDelivery.pending();
  portEXIT_CRITICAL(&wsDeliveryMux);
  return pending;
}

/** Retry the latest state independently for each client at a bounded rate. */
static void flushPendingPayload() {
  WsDelivery::Attempt attempt;
  portENTER_CRITICAL(&wsDeliveryMux);
  const bool ready = wsDelivery.prepare(micros(), attempt);
  portEXIT_CRITICAL(&wsDeliveryMux);
  if (!ready) return;

  // Network calls stay outside the lock shared with AsyncTCP callbacks.
  for (size_t i = 0; i < attempt.count; ++i) {
    const uint32_t id = attempt.clients[i];
    if (!ws.hasClient(id)) {
      portENTER_CRITICAL(&wsDeliveryMux);
      wsDelivery.disconnect(id);
      portEXIT_CRITICAL(&wsDeliveryMux);
      continue;
    }
    bool sent = false;
    if (ws.availableForWrite(id)) {
      sent = ws.binary(id, attempt.packet, sizeof(attempt.packet));
      if (!sent) ++wsDiscardCount;
    }
    portENTER_CRITICAL(&wsDeliveryMux);
    const bool close = wsDelivery.complete(attempt, i, sent);
    portEXIT_CRITICAL(&wsDeliveryMux);
    if (close) {
      Serial.printf("[ws] closing slow client id=%lu\n", (unsigned long)id);
      ws.close(id, 1013, "server busy");
      ++wsSlowCloseCount;
    }
  }
}

/** Summarize WebSocket/WiFi status at intervals to limit serial output. */
static void logWsDiagnostics() {
  uint32_t nowMs = millis();
  if (nowMs - lastWsDiagAtMs < 1000) {
    return;
  }

  lastWsDiagAtMs = nowMs;
  if (wsDiscardCount == 0 && wsDisconnectCount == 0 && wsSlowCloseCount == 0 &&
      wifiDisconnectCount == 0) {
    return;
  }

  Serial.printf("[ws] clients=%u pending=%u discards=%lu ws_disc=%lu slow_close=%lu wifi_disc=%lu\n",
                (unsigned)ws.count(), anyPendingPackets() ? 1U : 0U,
                (unsigned long)wsDiscardCount,
                (unsigned long)wsDisconnectCount,
                (unsigned long)wsSlowCloseCount,
                (unsigned long)wifiDisconnectCount);
  wsDiscardCount = 0;
  wsDisconnectCount = 0;
  wsSlowCloseCount = 0;
  wifiDisconnectCount = 0;
}

/** Update per-port connected/disconnected state from recent frame activity. */
static void refreshControllerConnectionState() {
  uint32_t nowMs = millis();

  for (size_t controller = 0; controller < N64_CONTROLLER_COUNT; ++controller) {
    if (!controllerConnected[controller]) {
      continue;
    }

    if ((uint32_t)(nowMs - controllerLastSeenMs[controller]) <=
        PORT_ACTIVITY_TIMEOUT_MS) {
      continue;
    }

    controllerConnected[controller] = false;
    controllerProbing[controller] = false;
    stopControllerRx(controller);
    Serial.printf("[port %u] disconnected (no poll traffic)\n",
                  (unsigned)(controller + 1));
  }
}

/**
 * Probe disconnected ports automatically. Keep RX stopped most of the time.
 * Use short probe windows to find controller lines with new activity.
 */
static void serviceControllerProbing() {
  uint32_t nowMs = millis();

  for (size_t controller = 0; controller < N64_CONTROLLER_COUNT; ++controller) {
    if (controllerConnected[controller]) {
      if (!controllerRxRunning[controller]) {
        startControllerRx(controller);
      }
      continue;
    }

    if (!controllerRxRunning[controller]) {
      if ((uint32_t)(nowMs - controllerLastProbeAtMs[controller]) <
          PORT_PROBE_INTERVAL_MS) {
        continue;
      }

      if (startControllerRx(controller)) {
        controllerProbing[controller] = true;
        controllerProbeStartedMs[controller] = nowMs;
        controllerLastProbeAtMs[controller] = nowMs;
      }
      continue;
    }

    if (controllerProbing[controller] &&
        (uint32_t)(nowMs - controllerProbeStartedMs[controller]) >=
            PORT_PROBE_WINDOW_MS) {
      controllerProbing[controller] = false;
      stopControllerRx(controller);
    }
  }
}

/** Queue initial snapshots through the same retry path as live updates. */
static void onWsEvent(AsyncWebSocket *server, AsyncWebSocketClient *client,
                      AwsEventType type, void *arg, uint8_t *data, size_t len) {
  if (type == WS_EVT_CONNECT) {
    client->setCloseClientOnQueueFull(false);
    portENTER_CRITICAL(&wsDeliveryMux);
    const bool tracked = wsDelivery.connect(client->id());
    portEXIT_CRITICAL(&wsDeliveryMux);
    if (!tracked) {
      Serial.printf("[ws] too many tracked clients; closing id=%lu\n",
                    (unsigned long)client->id());
      ws.close(client->id(), 1008, "too many clients");
      return;
    }
    Serial.printf("[ws] connect id=%lu from=%s\n", (unsigned long)client->id(),
                  client->remoteIP().toString().c_str());
  } else if (type == WS_EVT_DATA) {
    const uint64_t receivedUs = esp_timer_get_time();
    const auto *info = static_cast<AwsFrameInfo *>(arg);
    if (info->final && info->index == 0 && info->len == 4 &&
        info->opcode == WS_TEXT && len == 4 && memcmp(data, "ping", 4) == 0) {
      client->text("pong");
    } else if (info->final && info->index == 0 && info->len == len &&
               info->opcode == WS_TEXT && len > 5 && len <= 15 &&
               memcmp(data, "sync:", 5) == 0) {
      for (size_t i = 5; i < len; ++i)
        if (data[i] < '0' || data[i] > '9') return;
      char reply[80];
      snprintf(reply, sizeof(reply), "sync:%.*s:%llu:%llu", int(len - 5),
               reinterpret_cast<const char *>(data + 5),
               (unsigned long long)receivedUs,
               (unsigned long long)esp_timer_get_time());
      client->text(reply);
    }
  } else if (type == WS_EVT_DISCONNECT) {
    portENTER_CRITICAL(&wsDeliveryMux);
    wsDelivery.disconnect(client->id());
    portEXIT_CRITICAL(&wsDeliveryMux);
    ++wsDisconnectCount;
    Serial.printf("[ws] disconnect id=%lu from=%s\n",
                  (unsigned long)client->id(),
                  client->remoteIP().toString().c_str());
  }
}

/** Log WiFi link changes to compare their timing with browser disconnections. */
static void onWiFiEvent(WiFiEvent_t event, arduino_event_info_t info) {
  if (event == ARDUINO_EVENT_WIFI_STA_GOT_IP) {
    wifiLedConnected.store(true);
    Serial.printf("[wifi] got ip=%s\n", WiFi.localIP().toString().c_str());
  } else if (event == ARDUINO_EVENT_WIFI_STA_DISCONNECTED) {
    wifiLedConnected.store(false);
    // WiFiManager deliberately disconnects while changing credentials.
    if (info.wifi_sta_disconnected.reason != WIFI_REASON_ASSOC_LEAVE) {
      wifiLedFailures.fetch_add(1);
    }
    ++wifiDisconnectCount;
    Serial.printf("[wifi] disconnected reason=%d\n",
                  info.wifi_sta_disconnected.reason);
  }
}

/**
 * Start the ArduinoOTA listener for firmware uploads over WiFi.
 * mDNS already runs when this function starts. OTA adds its service to the existing responder.
 * The handlers below only log progress. The library writes the firmware and reboots.
 */
static void startOTA() {
  ArduinoOTA.setHostname(OTA_HOSTNAME);
  if (strlen(OTA_PASSWORD) > 0) {
    ArduinoOTA.setPassword(OTA_PASSWORD);
  }

  ArduinoOTA.onStart([]() {
    Serial.println("OTA update starting -- pausing controller sniffing.");
  });
  ArduinoOTA.onEnd([]() { Serial.println("\nOTA update complete; rebooting."); });
  ArduinoOTA.onProgress([](unsigned int done, unsigned int total) {
    Serial.printf("OTA progress: %u%%\r", (done * 100) / total);
  });
  ArduinoOTA.onError([](ota_error_t error) {
    Serial.printf("OTA error [%u]\n", error);
  });

  ArduinoOTA.begin();
  Serial.printf("OTA ready -- flash to %s.local\n", OTA_HOSTNAME);
}
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
void loop() {
  checkResetButton();
  serviceCommands();
  // Process any active OTA upload. This takes little time when idle.
  // An actual upload blocks here for a few seconds. Capture pauses, then the device reboots.
  ArduinoOTA.handle();
  flushPendingPayload();
  logWsDiagnostics();
  refreshControllerConnectionState();
  serviceControllerProbing();

#ifdef DEBUG_HEARTBEAT
  // Build with `-D DEBUG_HEARTBEAT` to check that the loop runs without console polls.
  // Otherwise, serial stays silent until a button changes.
  // Limit the heartbeat rate to keep other output readable.
  static uint32_t lastBeat = 0;
  if (millis() - lastBeat > 2000) {
    Serial.println("[idle] loop alive, waiting for N64 poll...");
    lastBeat = millis();
  }
#endif

  // Remove disconnected WebSocket clients at a limited rate. This takes little time when idle.
  static uint32_t lastCleanup = 0;
  if (millis() - lastCleanup > 1000) {
    ws.cleanupClients();
    lastCleanup = millis();
  }

  for (size_t controller = 0; controller < N64_CONTROLLER_COUNT; ++controller) {
    uint8_t frame[N64_FRAMEBITS];
    if (!readFrameFromRmt(controller, frame)) {
      continue;
    }
    if (!hasValidReservedBits(frame)) {
      continue;
    }

    const uint64_t decodedUs = esp_timer_get_time();
    uint8_t payload[4];
    packState(frame, payload);

    // Broadcast (and log) only on change per controller.
    if (memcmp(lastPayload[controller], payload, sizeof(payload)) != 0) {
      memcpy(lastPayload[controller], payload, sizeof(payload));
      portENTER_CRITICAL(&wsDeliveryMux);
      wsDelivery.update(controller, payload, decodedUs);
      portEXIT_CRITICAL(&wsDeliveryMux);
      printState(controller, decodeState(frame));
    }

    uint32_t nowMs = millis();
    controllerLastSeenMs[controller] = nowMs;
    if (!controllerConnected[controller]) {
      controllerConnected[controller] = true;
      controllerProbing[controller] = false;
      Serial.printf("[port %u] connected (poll traffic detected)\n",
                    (unsigned)(controller + 1));
    }
  }

  flushPendingPayload();
}

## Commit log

2026-09-07 Set onboard RGB LED to full-brightness red at startup
2026-09-07 docs: add console-powered N64 wiring diagram
2026-09-07 Add controller command mode for WiFi reset and power LED
    [main.cpp]
2026-09-07 docs: align wiring diagram with Super Mini pin layout
2026-09-13 Add tested v1.0 enclosure, soldering jig and Wi-Fi setup LED
    [Enclosure-full-enclosure-v1.0-Orca-complete.3mf, Enclosure-v1.0.FCStd, N64-Soldering-Jig-v1.3mf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]
2026-09-13 more wifi led changes
2026-09-13 remove cable
2026-09-14 save the verified v1.1 soldering jig release
    [N64-Soldering-Jig-v1.1.3mf, N64-Soldering-Jig-v1.1.FCStd]
2026-09-14 document the verified v1.1 CAD releases
2026-09-14 save the verified v1.1 enclosure release
    [Enclosure-full-enclosure-v1.1-Orca-complete.3mf, Enclosure-v1.1.FCStd]
2026-09-15 Save the verified v1.2 enclosure release
    [Enclosure-full-enclosure-v1.2-Orca-complete.3mf, Enclosure-v1.2.FCStd]
2026-09-15 Fix false N64 inputs with finer pulse timing
    [main.cpp]
2026-09-15 Fix empty UI response by streaming HTML from flash
    [main.cpp]
2026-09-15 track connection with a heartbeat
